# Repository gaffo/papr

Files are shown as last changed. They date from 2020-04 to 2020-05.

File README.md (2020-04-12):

# Gaffo PAPR

PAPR is a *P*owered *A*ir-*P*urifying *R*espirator. It is a hood with a supply that blows filtered air to a worker in a dirty environment. It is much less tiring to wear than masks or other methods.

This is my open documenation on research I have done into a PAPR device which can be hopefully used by others. All of this work is open source. Working on the licensing.

# Structure
This repository is broken up into eletrical, software, and mechanical sections. 

Electrical: Schematics, board layouts, etc for control boards and motors.
Software: Firmware, utilities, etc.
Mechanical: Enclosures, Test Rigs, Etc.

# Licensing

Due to how licensing works the different trees will likely have different licenses. Since everythign in this repo is currently just done by me, I feel free to relicense my work at any time.

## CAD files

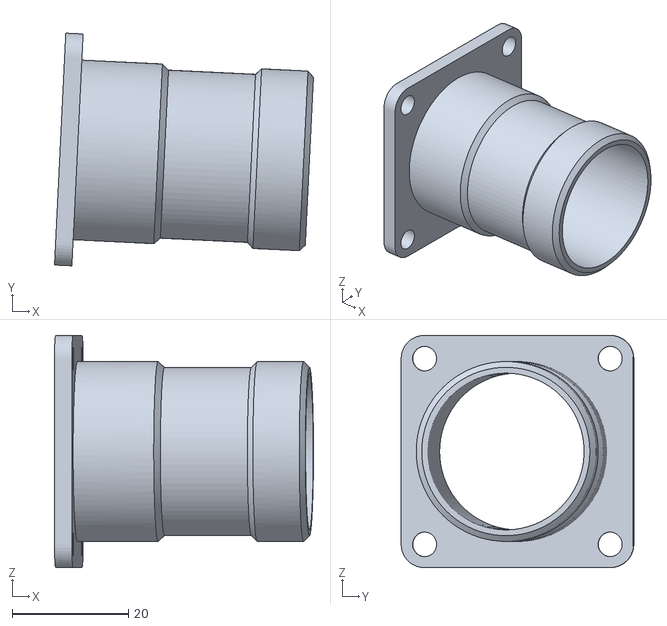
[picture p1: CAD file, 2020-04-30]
hardware/ammo_case/hose_mount.stl
44.6 x 40.1 x 40.0

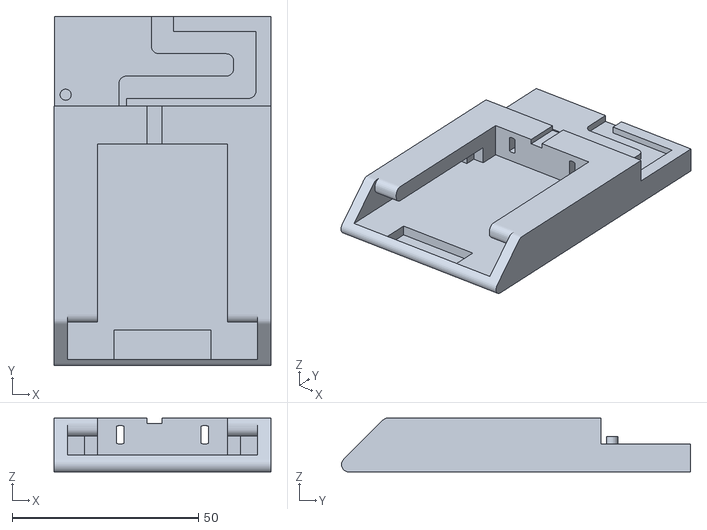
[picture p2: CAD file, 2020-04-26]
hardware/battery/bauer.stl
58.2 x 93.7 x 14.5

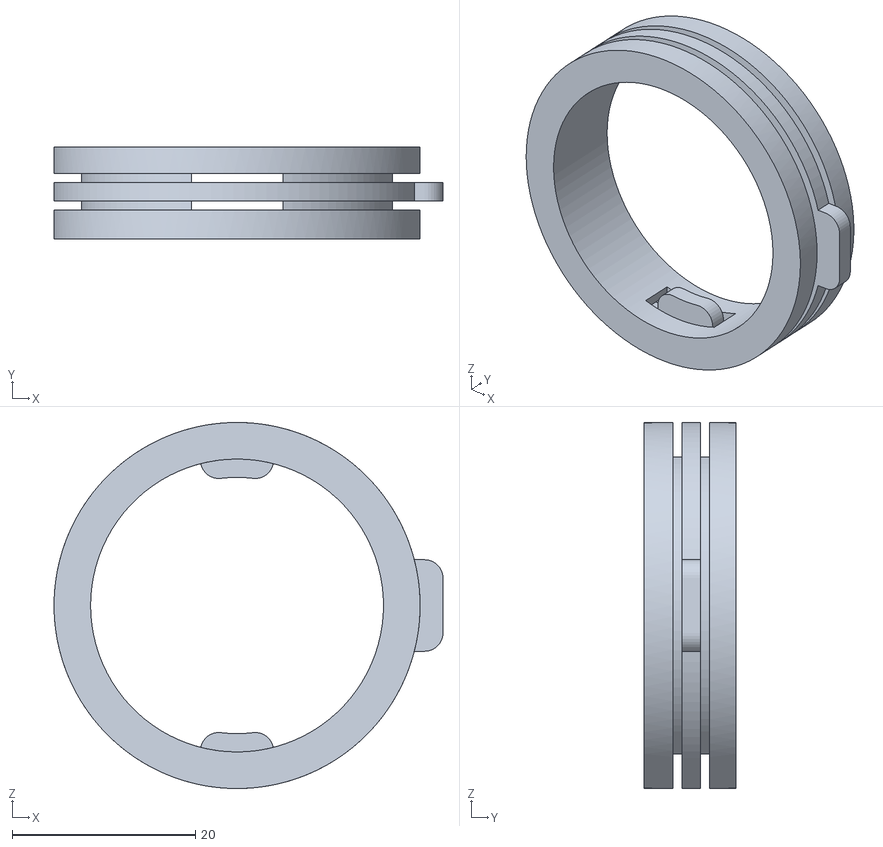
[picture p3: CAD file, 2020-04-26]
hardware/connectors/quick_connect_prototype.stl
42.5 x 10.0 x 40.0

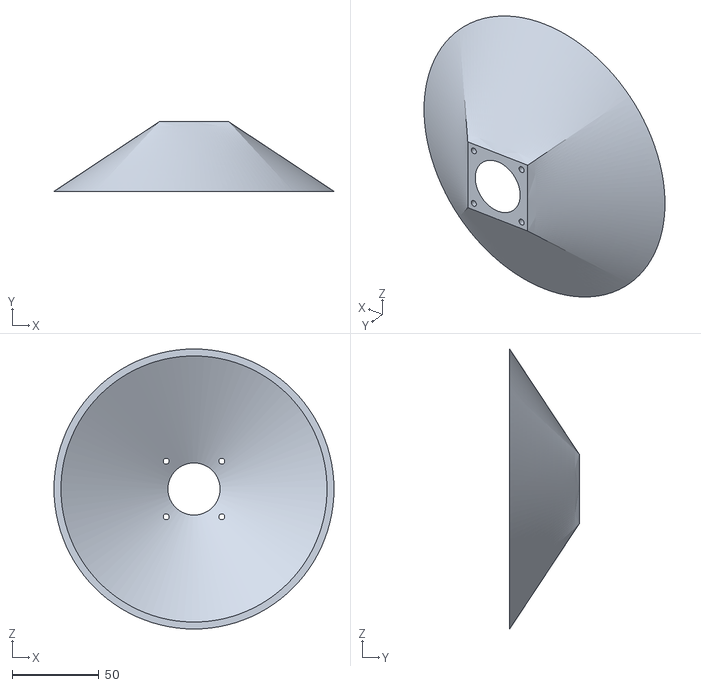
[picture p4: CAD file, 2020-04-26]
hardware/dyson_style/filter_flow_test.stl
161.0 x 40.0 x 161.0

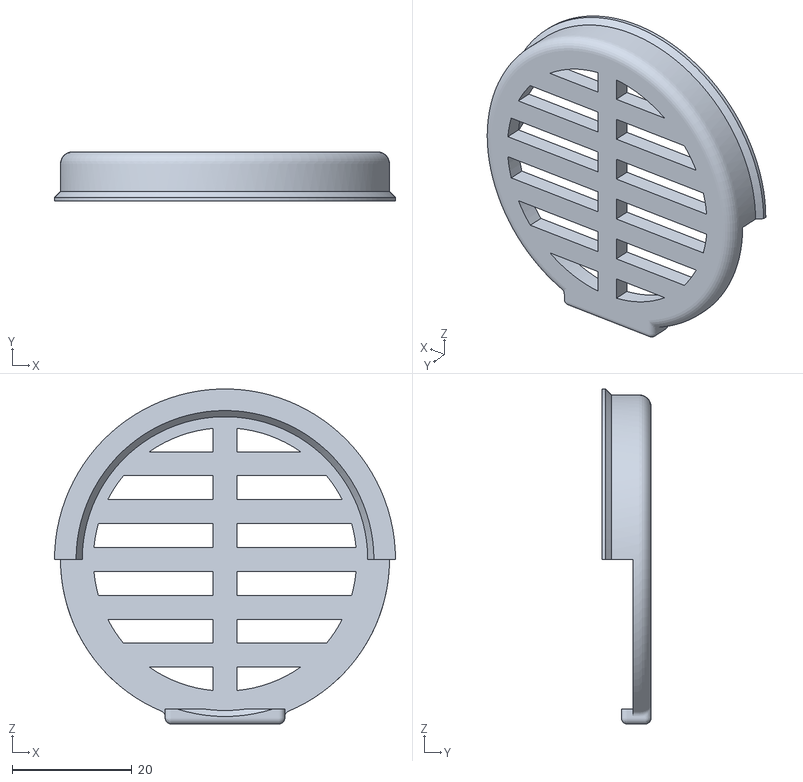
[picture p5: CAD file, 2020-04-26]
hardware/dyson_style/tests/filter_guard_clip/cover.stl
57.0 x 8.25 x 56.0

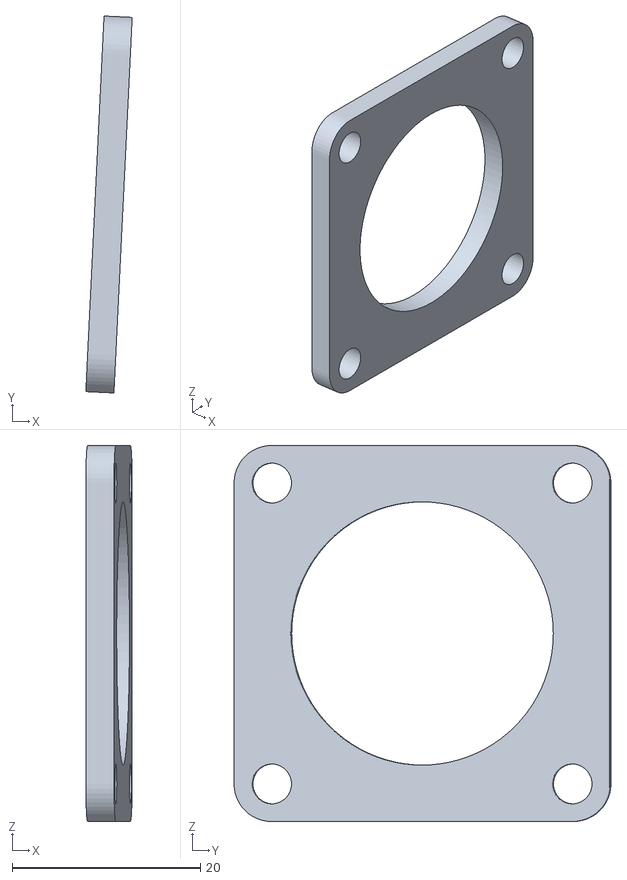
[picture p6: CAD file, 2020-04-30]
hardware/ammo_case/house_back_plate.stl
4.94 x 40.1 x 40.0

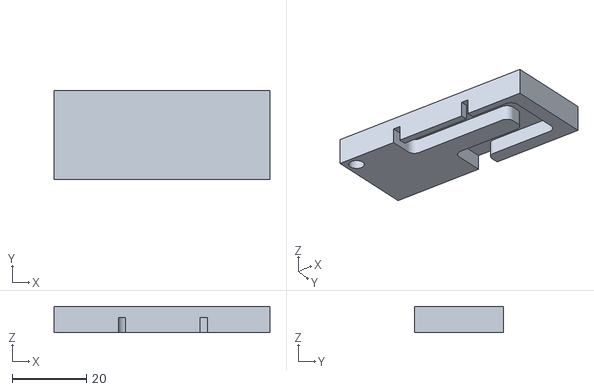
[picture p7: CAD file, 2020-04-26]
hardware/battery/bauer_cable_releif.stl
58.1 x 24.0 x 7.00

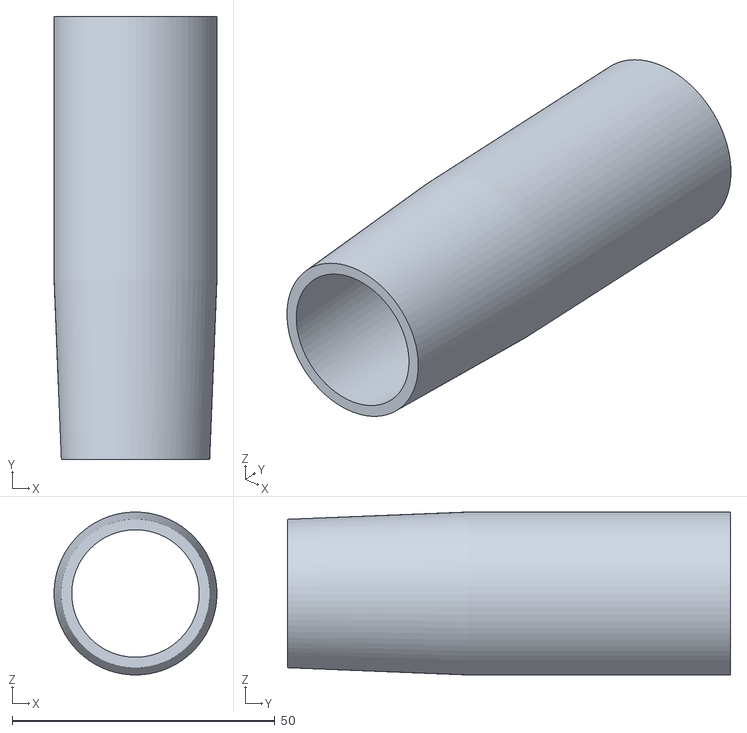
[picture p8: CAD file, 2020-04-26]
hardware/connectors/taper_1_inside.stl
31.0 x 84.3 x 31.0

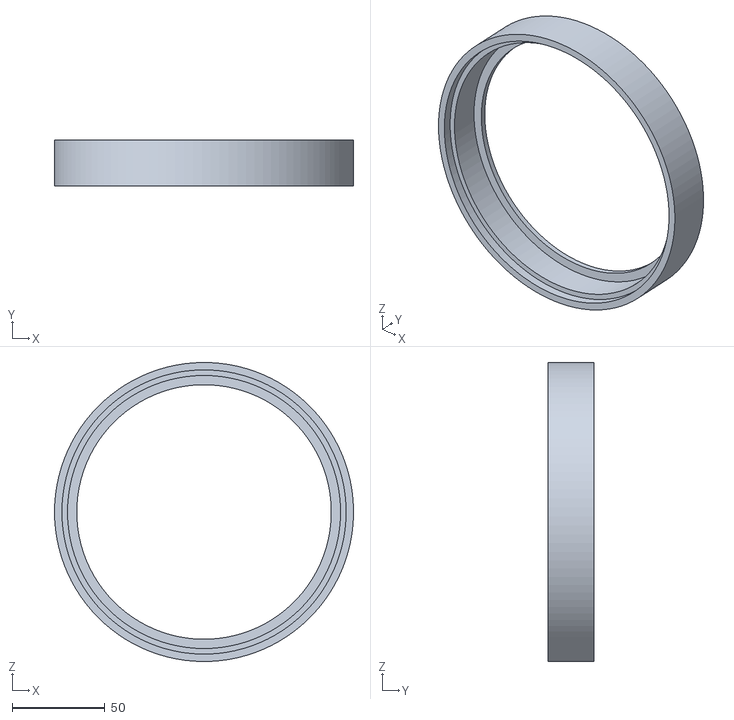
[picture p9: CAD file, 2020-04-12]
hardware/dyson_style/dyson_papr v3.stl
161.0 x 25.0 x 161.0

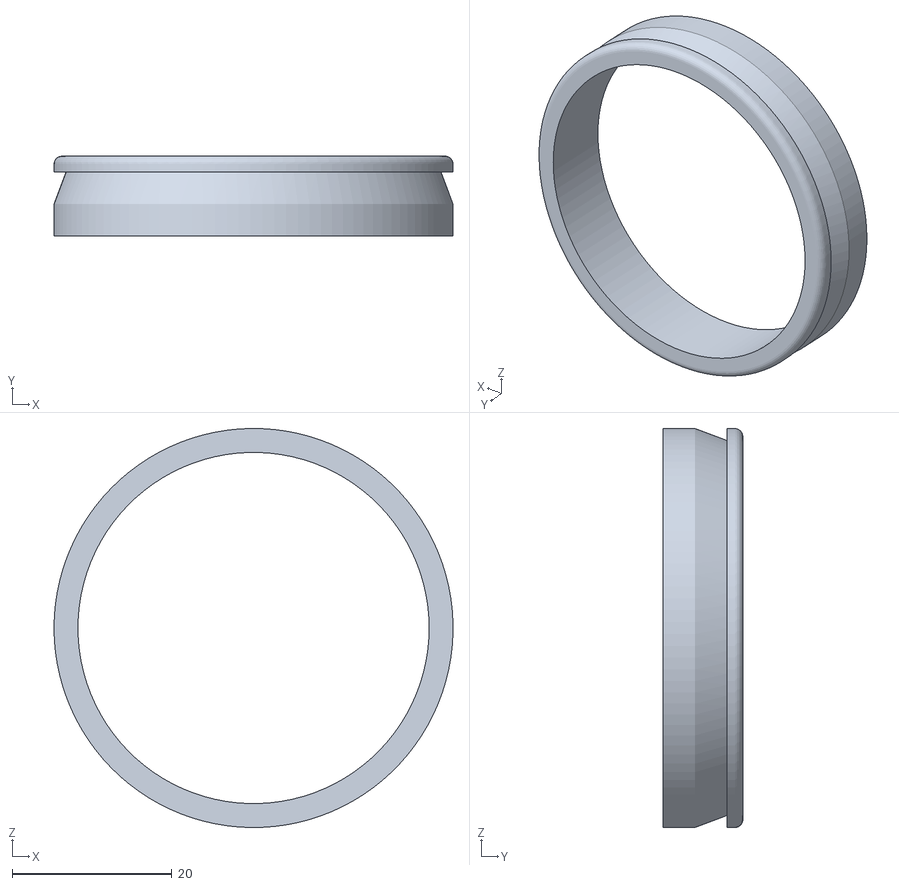
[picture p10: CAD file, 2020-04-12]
hardware/dyson_style/tests/filter_guard_clip/base.stl
50.0 x 10.0 x 50.0

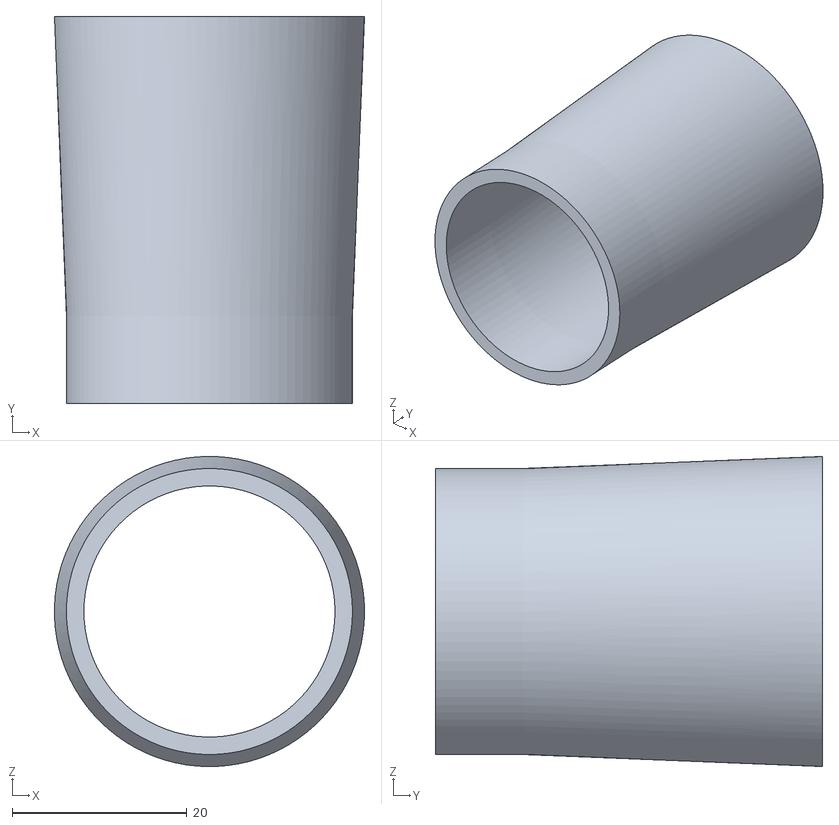
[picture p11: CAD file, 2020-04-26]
hardware/connectors/taper_1_outside.stl
35.5 x 44.3 x 35.5

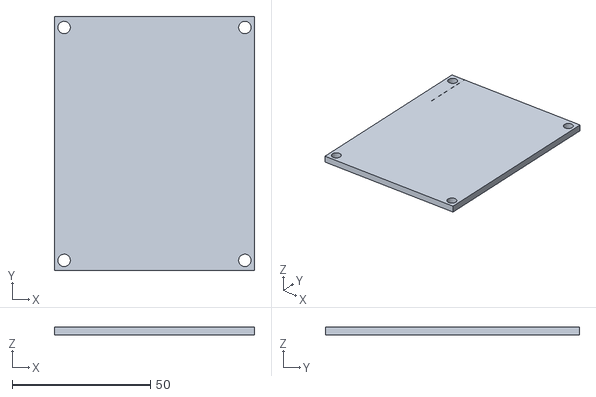
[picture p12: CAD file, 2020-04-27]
hardware/ammo_case/bauer_back_plate.stl
72.2 x 91.7 x 3.00

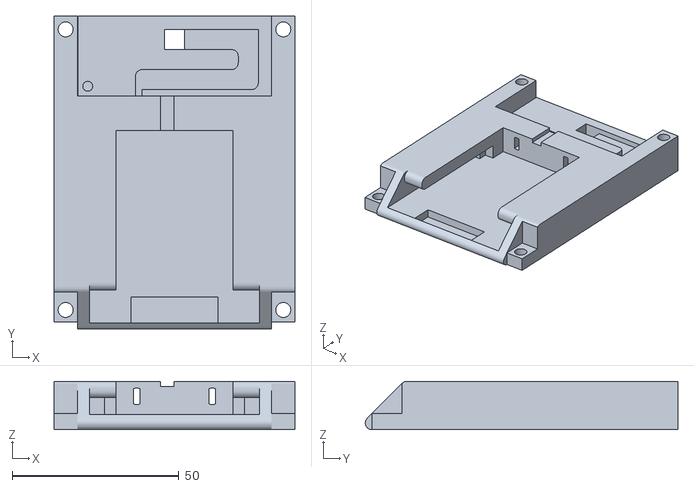
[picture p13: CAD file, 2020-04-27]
hardware/ammo_case/bauer_mount.stl
72.2 x 93.7 x 14.5

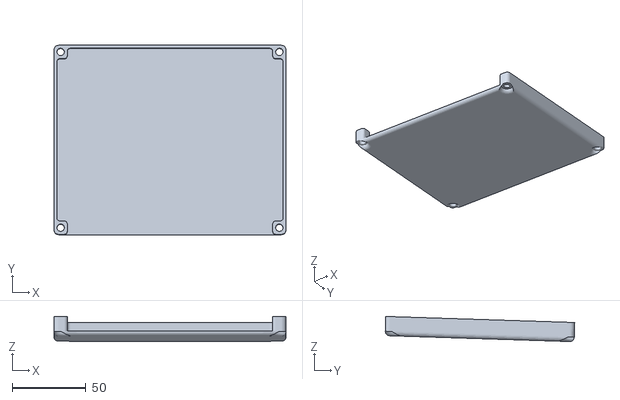
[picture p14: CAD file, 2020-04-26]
hardware/ammo_case/FilterCover.stl
157.0 x 128.3 x 17.0

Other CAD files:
hardware/ammo_case/bauer_closure.stl
hardware/dyson_style/enclosure.stl
hardware/ammo_case/OuterFilterMountPlate.stl
hardware/dyson_style/dyson_papr v3.f3d

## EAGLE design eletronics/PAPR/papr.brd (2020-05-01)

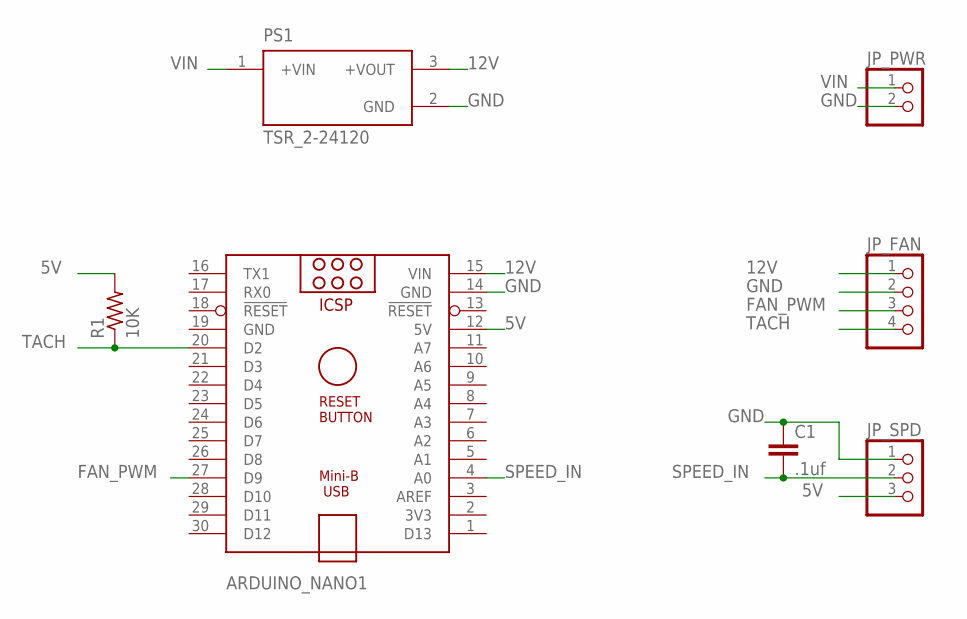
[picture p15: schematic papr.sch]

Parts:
ARDUINO_NANO1: ARDUINO_NANO
C1: .1uf; C2.5-3
JP_FAN: PINHD-1X4; 1X04
JP_PWR: PINHD-1X2; 1X02
JP_SPD: PINHD-1X3; 1X03
PS1: TSR_2-24120; CONV_TSR_2-24120
R1: 10K; 0204/5

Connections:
5V: ARDUINO_NANO1.12 (5V), JP_SPD.3, R1.2
12V: ARDUINO_NANO1.15 (VIN), JP_FAN.1, PS1.3 (+VOUT)
FAN_PWM: ARDUINO_NANO1.27 (D9), JP_FAN.3
GND: ARDUINO_NANO1.14 (GND), ARDUINO_NANO1.19 (GND), C1.1, JP_FAN.2, JP_PWR.2, JP_SPD.1, PS1.2 (GND)
SPEED_IN: ARDUINO_NANO1.4 (A0), C1.2, JP_SPD.2
TACH: ARDUINO_NANO1.20 (D2), JP_FAN.4, R1.1
VIN: JP_PWR.1, PS1.1 (+VIN)

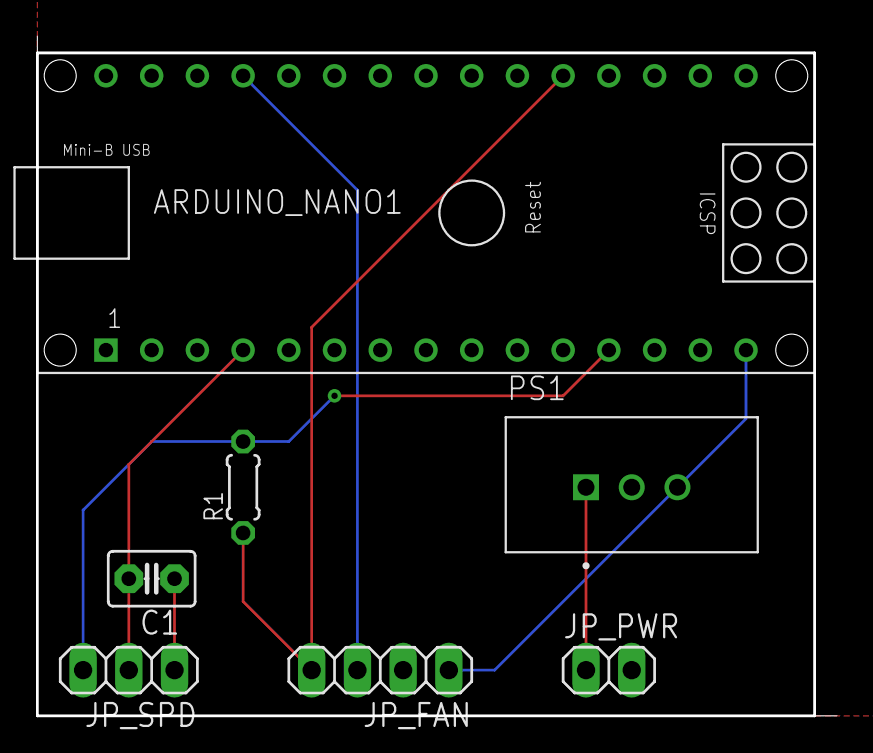
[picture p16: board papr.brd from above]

Board: 2 copper layers, 44.4 x 37.8 mm, 7 parts (0 on the bottom side), 7 nets.

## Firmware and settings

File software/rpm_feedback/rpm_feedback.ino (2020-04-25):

#include <TimerOne.h>
#include <AutoPID.h>
//#include <Arduino_DebugUtils.h>

int fanPin = 9;
int rpmFan = 2;

long lastSample = 0;
long rpmPulses = 0;

void rpmPulse() {
  rpmPulses++;
}

void setup() {
  // Setup pins and zero them out
  pinMode(fanPin, OUTPUT);
  pinMode(rpmFan, INPUT_PULLUP);
  lastSample = millis();
  attachInterrupt(digitalPinToInterrupt(rpmFan), rpmPulse, RISING);
  
  // setup PWM Module
  Timer1.initialize(40);
  Serial.begin(9600);
//  Debug.timestampOn();
  while (!Serial) {
    ; // wait for serial port to connect. Needed for native USB port only
  }
}

void loop() {
  delay(100);
  Serial.println(rpmPulses);
  long delta = long(millis() - lastSample);

  double rpMs = (rpmPulses / double(delta)); // to minutes
  rpmPulses = 0;
  lastSample = millis();
  
  float val = float(10.0 / 100.0) * 1023;
  Timer1.pwm(fanPin, val);
}

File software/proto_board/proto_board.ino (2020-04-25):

#include <TimerOne.h>

int fanPin = 9;

void setup() {
  // Setup pins and zero them out
  pinMode(LED_BUILTIN, OUTPUT);
  pinMode(fanPin, OUTPUT);
  
  // setup PWM Module
  Timer1.initialize(40);
}

const int d = 500;

void loop() {
  // slowly increase the PWM fan speed
  for (float dutyCycle = 0.0; dutyCycle < 100.0; dutyCycle++) {
    Serial.print("PWM Fan, Duty Cycle = ");
    Serial.println(dutyCycle);
    Timer1.pwm(fanPin, (dutyCycle / 100) * 1023);
//    analogWrite(fanPin, (dutyCycle / 100) * 255);
    delay(d);
  }
  for (float dutyCycle = 100; dutyCycle > 0.0; dutyCycle--) {
    Serial.print("PWM Fan, Duty Cycle = ");
    Serial.println(dutyCycle);
    Timer1.pwm(fanPin, (dutyCycle / 100) * 1023);
//    analogWrite(fanPin, (dutyCycle / 100) * 255);
    delay(d);
  }
}

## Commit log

2020-04-12 Setting up basic repo
    [base.stl, cover.stl, dyson_papr v3.f3d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]
2020-04-25 Working up pid control of the fan
2020-04-25 working on rpm feedbac, I think there's a hwardwrae issue
    [rpm_feedback.ino]
2020-04-26 HArdware updates
    [FilterCover.stl, OuterFilterMountPlate.stl, bauer.stl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]
2020-04-27 Made battery mount and working on basic electronics
    [bauer_back_plate.stl, bauer_closure.stl, bauer_mount.stl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]
2020-05-01 Added pullup resistor
    [papr.brd, papr.sch]
2020-05-01 Routed fan pwm solely on the bottom layer, had pointless short top trace
    [papr.brd]
